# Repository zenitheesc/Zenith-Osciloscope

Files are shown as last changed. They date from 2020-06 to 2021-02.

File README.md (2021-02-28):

<h1 align="center" style="color:white; background-color:black">Zenith Osciloscope</h1>
<h4 align="center">This project is an educational oscilloscope based on STM32F103C8T6 aimed to be used by students on PC laboratories. The oscilloscope get some samples in a small frequency limited by the range in the STM AD converter. This samples was stored in a data pack on STM and passed by serial communication to PC. In the PC, a interface software read the serial and plot the data package</h4>

<p align="center">
	<a href="http://zenith.eesc.usp.br/">
    
    </a>
    <a href="https://eesc.usp.br/">
    
    </a>
    <a href="https://github.com/zenitheesc/Zenith-Osciloscope/blob/main/LICENSE">
    
    </a>
    <a href="https://github.com/zenitheesc/Zenith-Osciloscope/issues">
    
    </a>
    <a href="https://github.com/zenitheesc/Zenith-Osciloscope/commits/main">
    
    </a>
    <a href="https://github.com/zenitheesc/Zenith-Osciloscope/graphs/contributors">
    
    </a>
    <a href="https://github.com/zenitheesc/Zenith-Osciloscope/commits/main">
    
    </a>
    <a href="https://github.com/zenitheesc/Zenith-Osciloscope/issues">
    
    </a>
    <a href="https://github.com/zenitheesc/Zenith-Osciloscope/pulls">
    
    </a>
</p>



---

<p align="center">
    <a href="http://zenith.eesc.usp.br">
    
    </a> 
    <a href="https://www.facebook.com/zenitheesc">
    
    </a> 
    <a href="https://www.instagram.com/zenith_eesc/">
    
    </a>

</p>
<p align = "center">
<a href="zenith.eesc@gmail.com">zenith.eesc@gmail.com</a>
</p>

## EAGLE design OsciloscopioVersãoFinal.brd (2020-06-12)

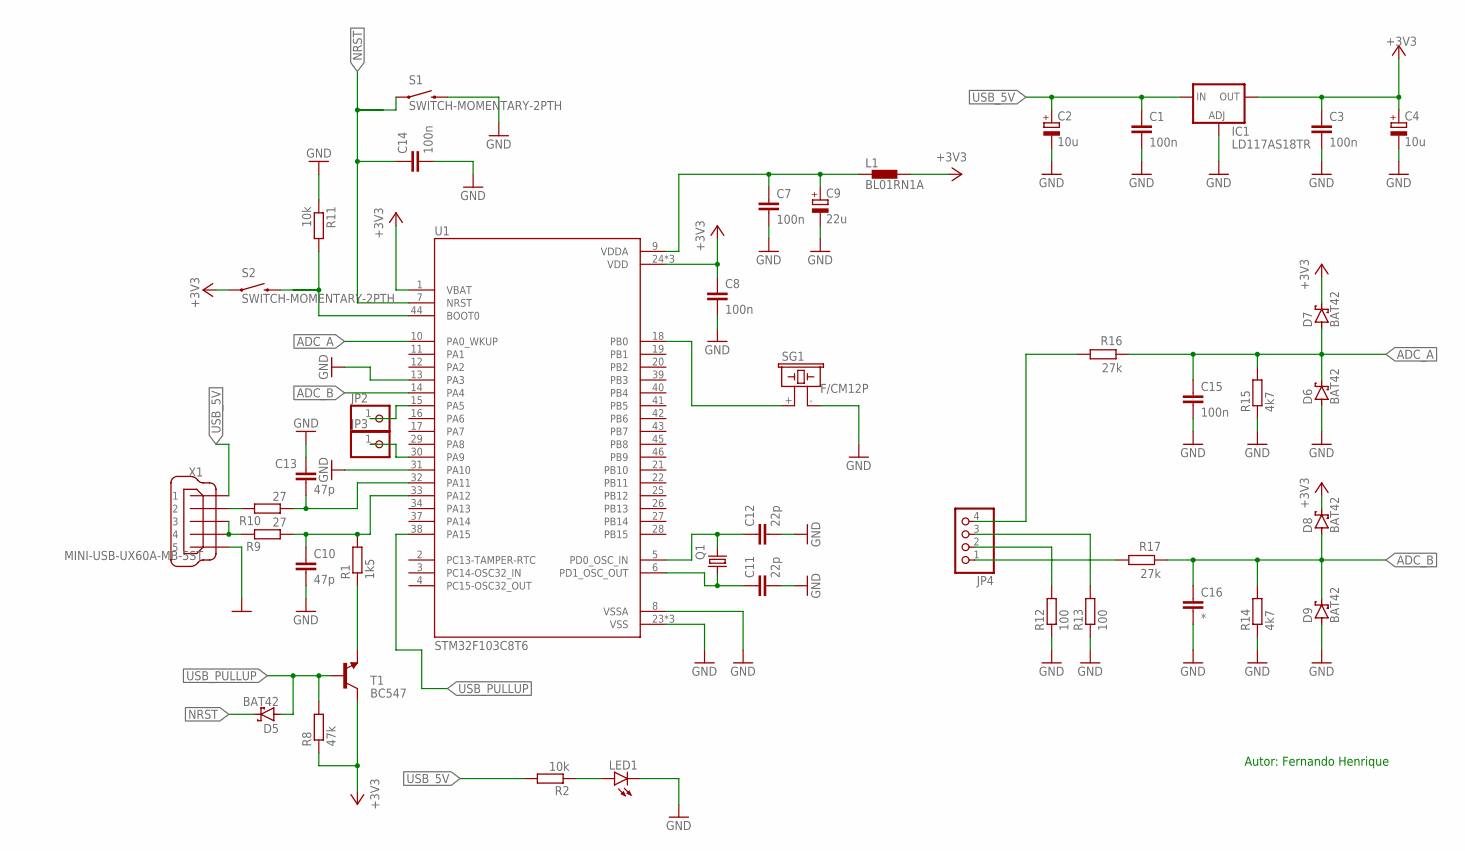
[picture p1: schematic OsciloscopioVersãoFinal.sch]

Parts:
C1, C3, C7, C8, C14, C15: 100n; C1206
C2, C4: 10u; B45181B
C9: 22u; B45181B
C10, C13: 47p; C1206
C11, C12: 22p; C1206
C16: *; C1206
D5, D6, D7, D8, D9: BAT42; DO35-10
IC1: LD117AS18TR; SOT223
JP2, JP3: PINHD-1X1; 1X01
JP4: PINHD-1X4; 1X04
L1: BL01RN1A
LED1: LED3MM
Q1: CRYSTALHC49U-V; HC49U-V
R1: 1k5; R1206
R2, R11: 10k; R1206
R8: 47k; R1206
R9, R10: 27; R1206
R12, R13: 100; R1206
R14, R15: 4k7; R1206
R16, R17: 27k; R1206
S1, S2: SWITCH-MOMENTARY-2PTH; TACTILE-PTH
SG1: F/CM12P
T1: BC547; TO92
U1: STM32F103C8T6; QFP50P900X900X160-48N
X1: MINI-USB-UX60A-MB-5ST; UX60A-MB-5ST

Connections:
+3V3: C3.1, C4.+, C8.1, D7.C, D8.C, IC1.4 (OUT), L1.2, R8.1, S2.1, T1.3 (C), U1.1 (VBAT), U1.24 (VDD), U1.36 (VDD), U1.48 (VDD)
ADC_A: C15.1, D6.C, D7.A, R15.2, R16.1, U1.10 (PA0_WKUP)
ADC_B: C16.1, D8.A, D9.C, R14.2, R17.1, U1.14 (PA4)
GND: C1.2, C2.-, C3.2, C4.-, C7.2, C8.2, C9.-, C10.2, C11.2, C12.2, C13.1, C14.2, C15.2, C16.2, D6.A, D9.A, IC1.1 (ADJ), LED1.K (C), R11.1, R12.1, R13.1, R14.1, R15.1, S1.3 (2), SG1.- (2), U1.8 (VSSA), U1.13 (PA3), U1.23 (VSS), U1.31 (PA10), U1.35 (VSS), U1.47 (VSS), X1.5
unnamed: LED1.A, R2.1
unnamed: SG1.+ (1), U1.18 (PB0)
unnamed: C13.2, R10.1, U1.32 (PA11)
unnamed: C10.1, R1.2, R9.1, U1.33 (PA12)
unnamed: C7.1, C9.+, L1.1, U1.9 (VDDA)
unnamed: C11.1, Q1.1, U1.6 (PD1_OSC_OUT)
unnamed: C12.1, Q1.2, U1.5 (PD0_OSC_IN)
unnamed: R1.1, T1.1 (E)
unnamed: R10.2, X1.2
unnamed: R9.2, X1.3, X1.4
unnamed: JP2.1, U1.15 (PA5)
unnamed: JP3.1, U1.30 (PA9)
unnamed: R11.2, S2.3 (2), U1.44 (BOOT0)
unnamed: JP4.1, R17.2
unnamed: JP4.2, R12.2
unnamed: JP4.3, R13.2
unnamed: JP4.4, R16.2
NRST: C14.1, D5.C, S1.1, U1.7 (NRST)
USB_5V: C1.1, C2.+, IC1.3 (IN), R2.2, X1.1
USB_PULLUP: D5.A, R8.2, T1.2 (B), U1.38 (PA15)

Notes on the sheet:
Autor: Fernando Henrique

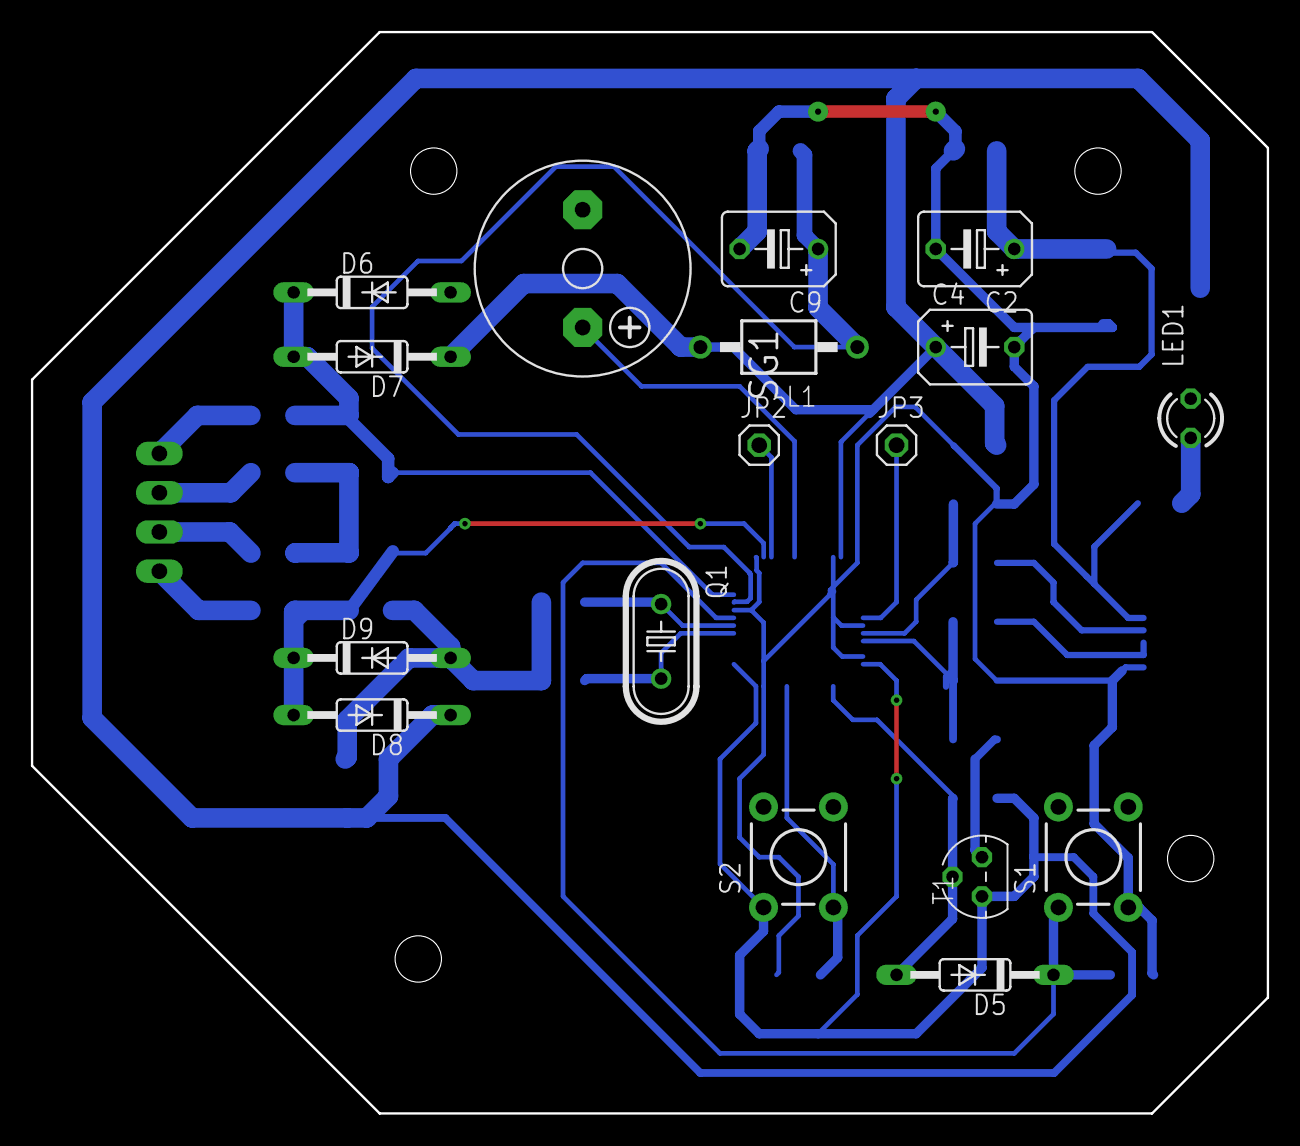
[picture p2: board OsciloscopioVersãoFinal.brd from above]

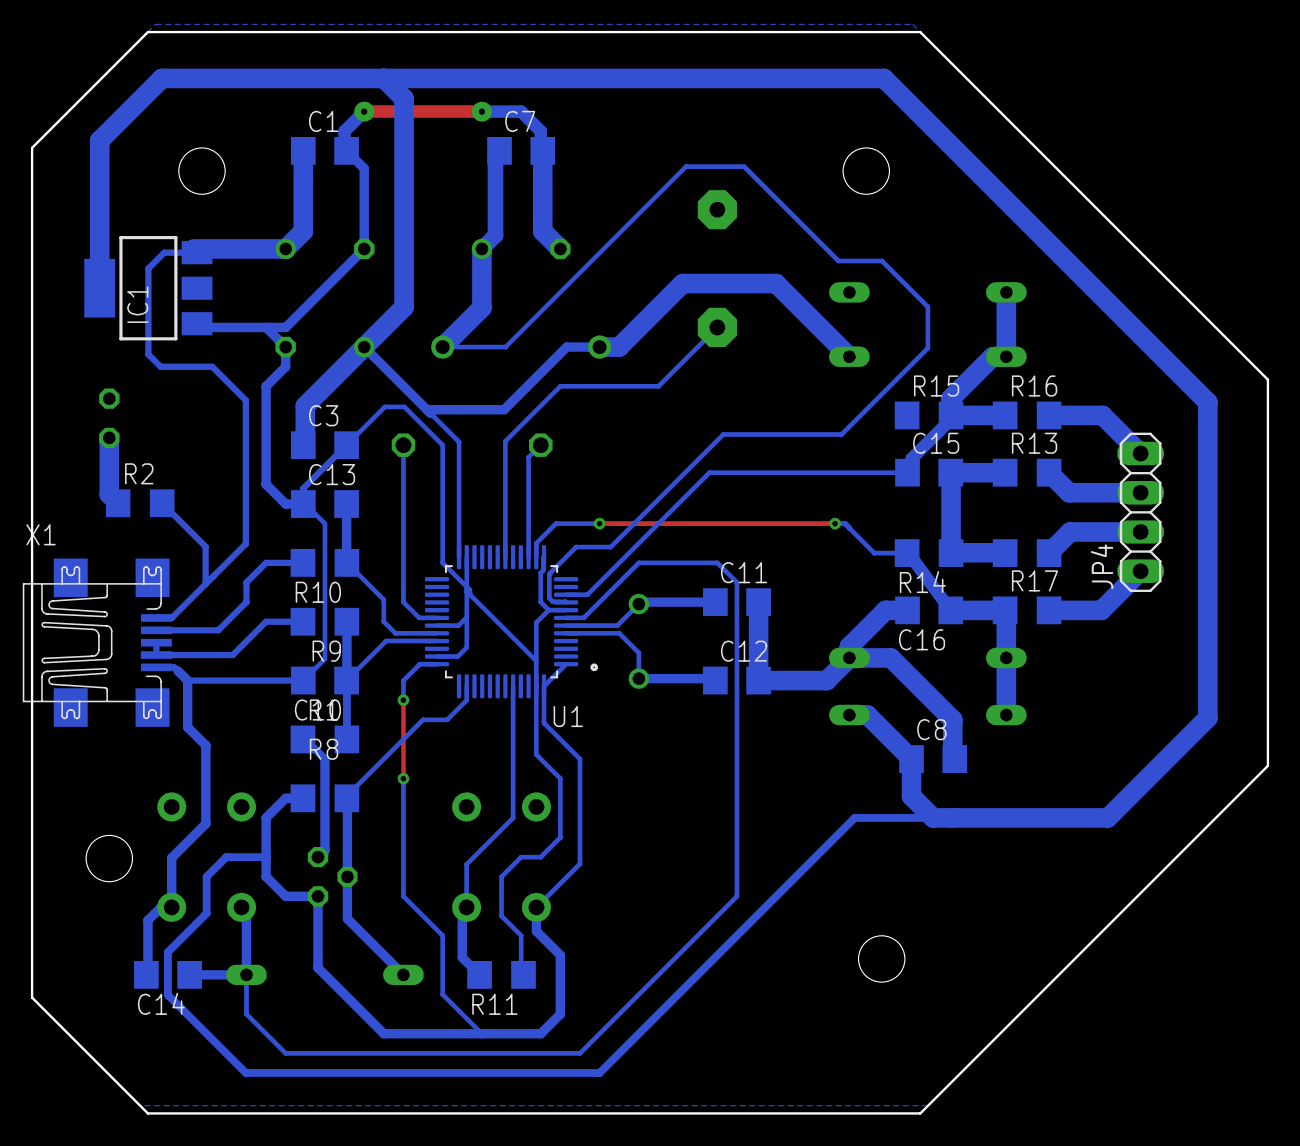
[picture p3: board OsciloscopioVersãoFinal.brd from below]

Board: 2 copper layers, 80.0 x 70.0 mm, 44 parts (27 on the bottom side), 24 nets.

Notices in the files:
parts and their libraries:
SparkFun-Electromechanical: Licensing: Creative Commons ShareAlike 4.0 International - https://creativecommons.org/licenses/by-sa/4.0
